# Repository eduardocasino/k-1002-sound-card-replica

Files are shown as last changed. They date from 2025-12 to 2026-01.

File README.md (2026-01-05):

# K-1002 8 bit audio Digital to Analog Converter replica

## About

This is a faithful replica of the K‑1002 8‑bit audio Digital‑to‑Analog Converter card for the KIM‑1, SYM‑1, and AIM‑65 computers, originally designed by MTU in the late ’70s.

I'm using the original K‑1002 documentation and high‑resolution photos from [Hans Otten's Retro Computing website](http://retro.hansotten.nl/).

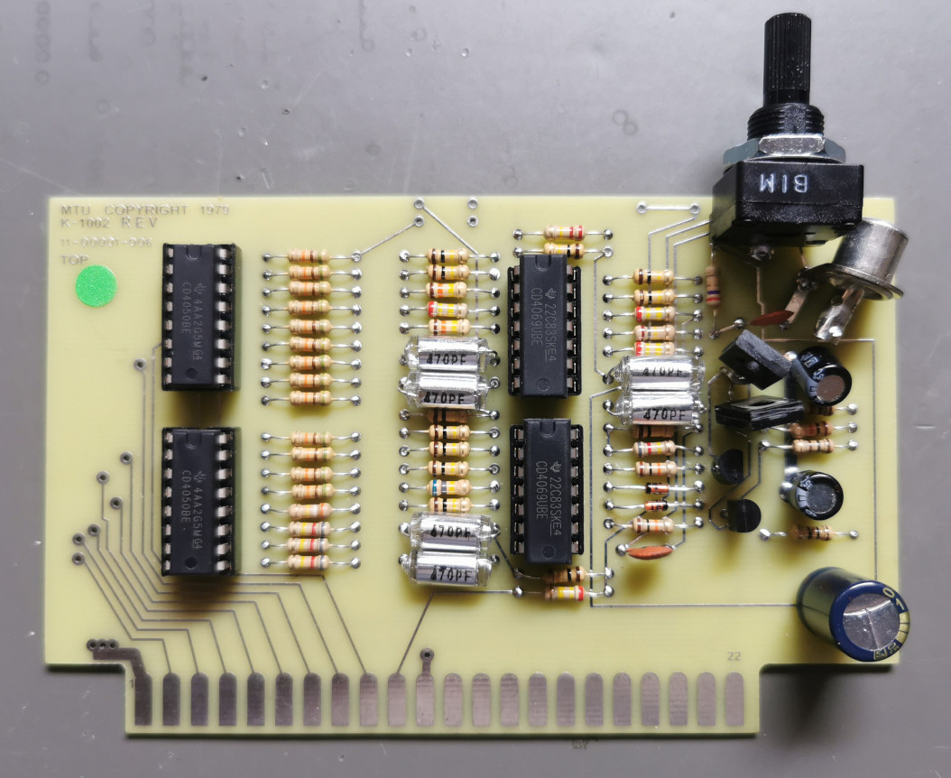
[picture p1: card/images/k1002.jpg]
finished card

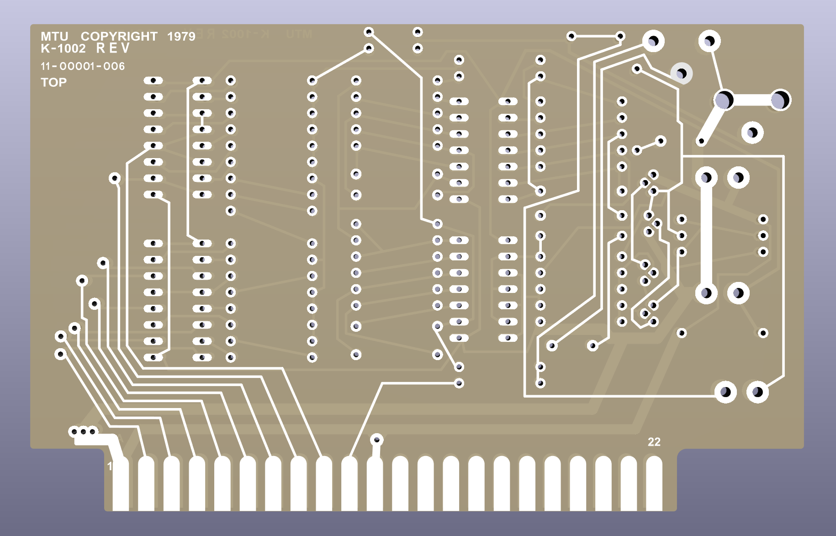
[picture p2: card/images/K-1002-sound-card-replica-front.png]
front

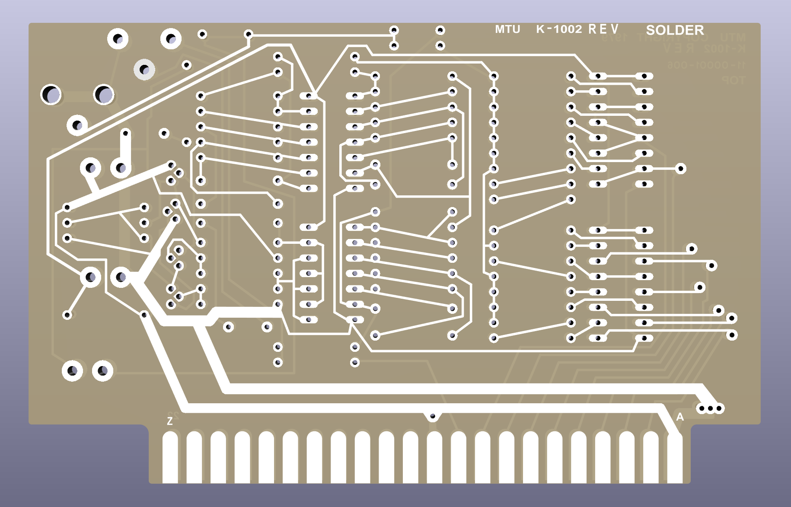
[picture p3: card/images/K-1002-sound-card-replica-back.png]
back


### Important!

Although the card uses the familiar 44‑pin edge connector, it’s not a 1‑to‑1 match for the KIM‑1 application bus, so an adapter is required, as explained in the manual. I’ve also designed such an adapter, which you can find in the `adapter` folder.

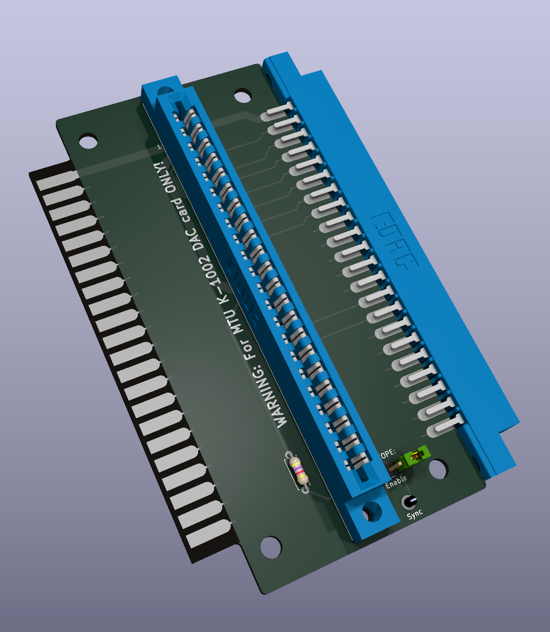
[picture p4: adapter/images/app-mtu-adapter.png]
adapter


## Building

There’s nothing particularly special about assembling the board. As with any other PCB, just start soldering components in order of height. All the ICs are socketed.

There’s a BOM spreadsheet in the `card/docs` folder, but there are a few things to keep in mind regarding some of the components:

* R1 to R13 are 51K resistors that need to be matched within 1%. You can either use modern metal‑film resistors with that tolerance or manually match carbon ones. I went with the latter to keep the look closer to the original.
Also, the documentation isn’t very clear about whether &plusmn;1% is actually enough or if it really means &plusmn;0.5% (so that all resistors fall within a 1% spread). I chose the latter interpretation as well.

* The 92PU01 and 92PU51 transistors are no longer available. The BD135‑10 and BD136‑10 are perfectly good functional replacements, but they use a different package and footprint, so you’ll need to bend the leads to fit them on the board.
 **NOTE**: They *must* be the "-10" variants!!

* The original potentiometer is no longer manufactured. A drop‑in replacement is the Piher PT15NH06 with the adjustment wheel. **NOTE**: Make sure you get the NH06 variant.

* The Keystone 571 RCA connector is no longer manufactured. Some suppliers may still have remaining stock, such as [TME](https://tme.eu) in Europe.

## KIM-1 Software and PC Utilities

I've only built it on a Debian Linux and on WSL with Ubuntu. I can't give support for other systems, sorry.

### Prerequisites

Any modern Linux distribution, tested on `Debian 12.6` and `Ubuntu 24.04`

Install the required packages:

```console
$ sudo apt update
$ sudo apt install build-essential cc65
```

### Build and usage

Just go to the `software` folder and run`make`:

```console
$ cd software
$ make
```

This will build the PC utilities and the KIM‑1 demo programs. The latter are generated in PAP format and are named with a numeric prefix that matches the file numbers in the K‑1002‑1L 8‑BIT Digital Music Software manual. Use them as instructed there.

Additionally, pcmplay.pap is a simple PCM player that plays a short sound snippet. Load it into your KIM-1 and run it at `$0200`.

The PC utilities are built into `software/utils/bin`:

* `wavegen` is a modern C version of the `kimfs` program. It generates a waveform table suitable for use with the MTU utilities from a very simle YAML description file.

* `notcmp` is the C version of the NOTRAN compiler. It accepts the same input files as its MTU counterpart and generates compatible object code for the NOTRAN interpreter.

* `notint` is a NOTRAN interpreter simulator that can either play a NOTRAN bytecode file through an ALSA device or generates WAV files to be played with any WAV player.

Run any of them without arguments to see the usage instructions.

## Licensing

This is a personal project that I am sharing in case it is of interest to any retrocomputing enthusiast and all the information in this repository is provided "as is", without warranty of any kind. I am not liable for any damages that may occur, whether it be to individuals, objects, KIM-1 computers, kittens or any other pets. **It should also be noted that everything in this repository is a work in progress and, although the board has been tested, may contain errors. Therefore, anyone who chooses to use it does so at their own risk**.

### Card



Th K-1002 replica is licensed under a [Creative Commons Attribution-NonCommercial 4.0 International License](http://creativecommons.org/licenses/by-nc/4.0/).

### Adapter



The adapter card is licensed under a [Creative Commons Attribution-ShareAlike 4.0 International License](http://creativecommons.org/licenses/by-sa/4.0/).

### MTU Software

Although it probably doesn’t matter much nowadays, since this software was written for a very obsolete and rare piece of hardware, the material is still copyrighted by MICRO TECHNOLOGY UNLIMITED, a company that is [still in business](http://www.mtu.com/catalog/index.php). I’m sharing it here solely to help anyone who owns a K‑1002 card.

### PC Utilities

All my code is licensed under the GNU General Public License, Version 3.

## Acknowledgements

* Hans Otten and his [Retro Computing blog](http://retro.hansotten.nl/). A lot of information and high resolution pictures of a K-1002

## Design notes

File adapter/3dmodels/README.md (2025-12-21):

Download the EDAC connector 3D model from here: https://files.edac.net/edac/content/307/307-044-520-202%20-%20EDAC%20Card%20Edge%20Connector.STEP

Jumper model by 
Dmitry Levin https://grabcad.com/library/jumper-2-54mm-pitch-1

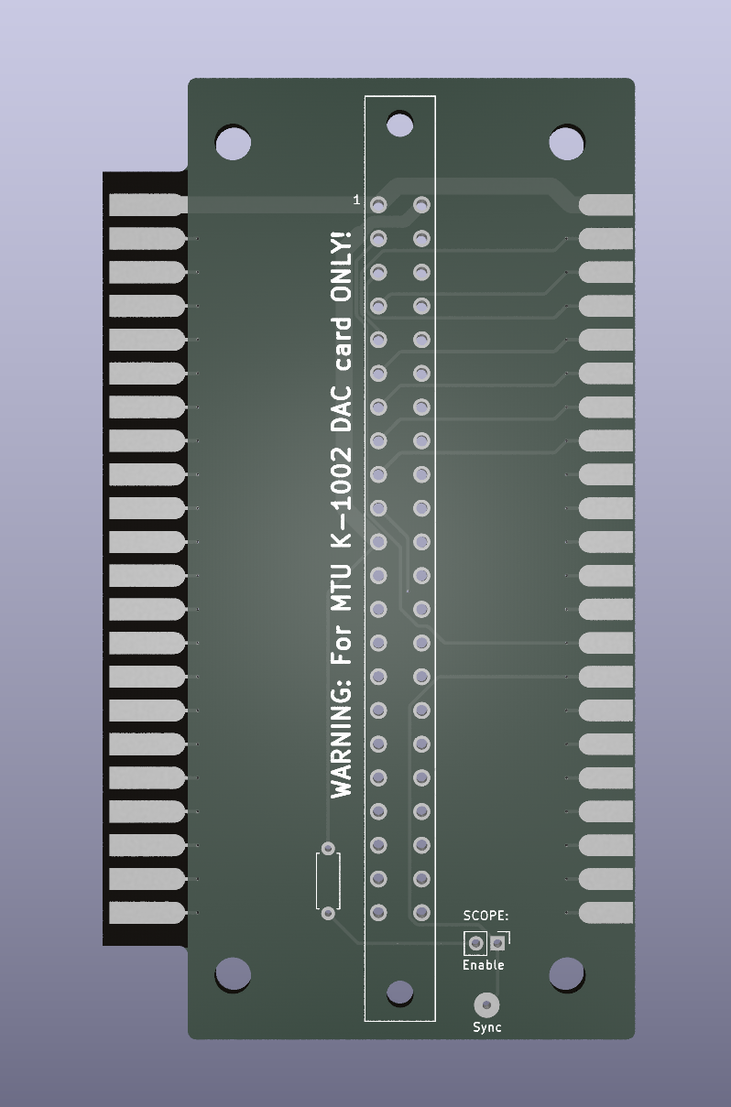
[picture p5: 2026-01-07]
adapter/images/app-mtu-adapter-front.png

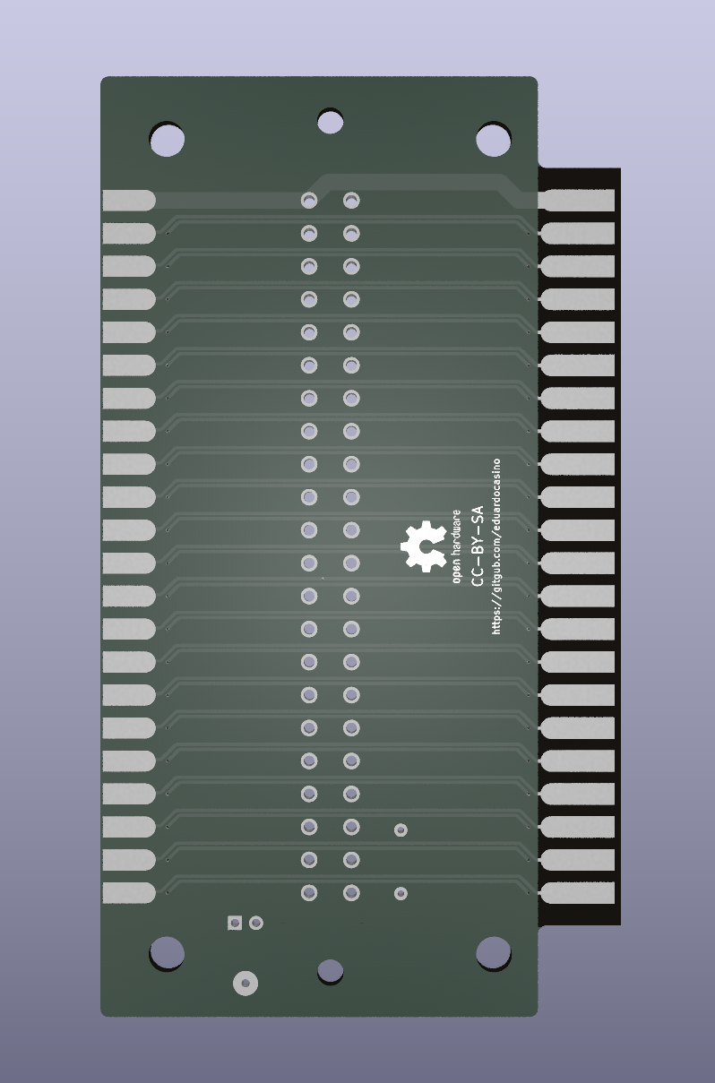
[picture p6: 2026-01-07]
adapter/images/app-mtu-adapter-back.png

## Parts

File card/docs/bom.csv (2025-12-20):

Reference | Qty | Type | Value | Notes
C1,C2,C3,C4,C5,C6 | 6 | polystyrene | 470p
C7,C9 | 2 | ceramic, 12V, Z5U | 100n
C8 | 1 | electrolytic, 10V | 1000u
C10,C11 | 2 | electrolytic, 6V | 220u
D1,D2 | 2 |  | 1N4148
P1 | 1 | RCA Keystone 571
Q1 | 1 |  | PN2907
Q2 | 1 |  | PN2222
Q3 | 1 |  | 92PU01 | Alternative: | BD135-10
Q4 | 1 |  | 92PU51 | Alternative: | BD136-10
R1,R2,R3,R4,R5,R6,R7,R8,R9,R10,R11,R12,R13 | 13 | Carbon, 0.25W | 51K | Matched to 1%
R14 | 1 | Carbon, 0.25W | 390K
R15,R16,R17,R38 | 4 | Carbon, 0.25W | 820K
R18,R19,R23,R24,R25,R26,R28,R30,R31,R32,R33,R37 | 12 | Carbon, 0.25W | 100K
R20,R22 | 2 | Carbon, 0.25W | 130K
R21,R34,R36,R45 | 4 | Carbon, 0.25W | 240K
R27 | 1 | Carbon, 0.25W | 680K
R29 | 1 | Carbon, 0.25W | 220K
R35 | 1 | Carbon, 0.25W | 180K
R39,R40 | 2 | Carbon, 0.25W | 10K
R41,R43 | 2 | Carbon, 0.25W | 100R
R42 | 1 | Carbon, 0.25W | 1K
R44 | 1 | Carbon, 0.25W | 10R
R46 | 1 | Carbon, 0.25W | 2R7
R47 | 1 | Piher PT15NH06 | 1M | Alternative: | 16PMI-1MSR PASSIVES
U1,U2 | 2 |  | CD4050
U3,U4 | 2 |  | CD4069

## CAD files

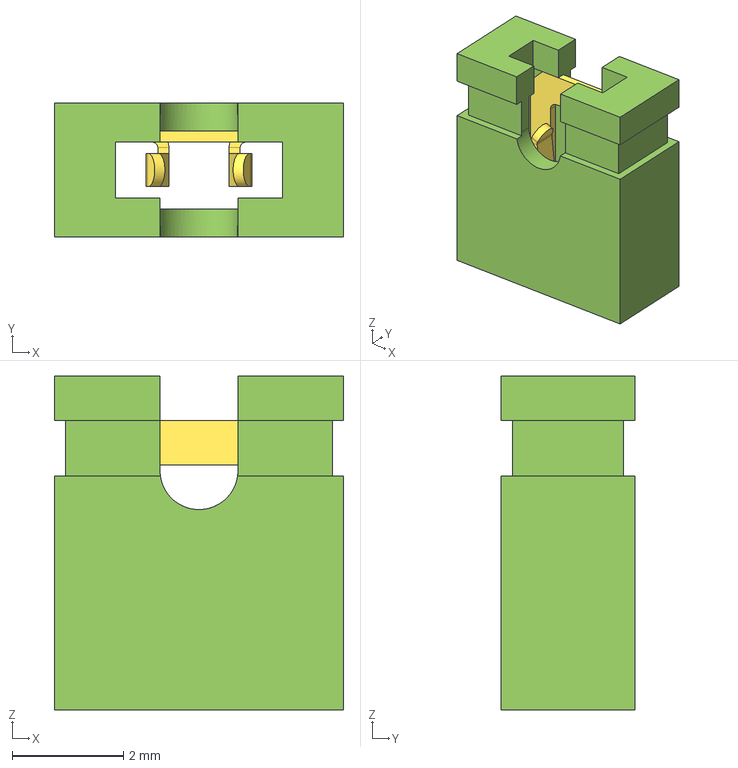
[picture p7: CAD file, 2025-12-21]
adapter/3dmodels/Jumper-green.step
5.20 x 2.40 x 6.00 mm

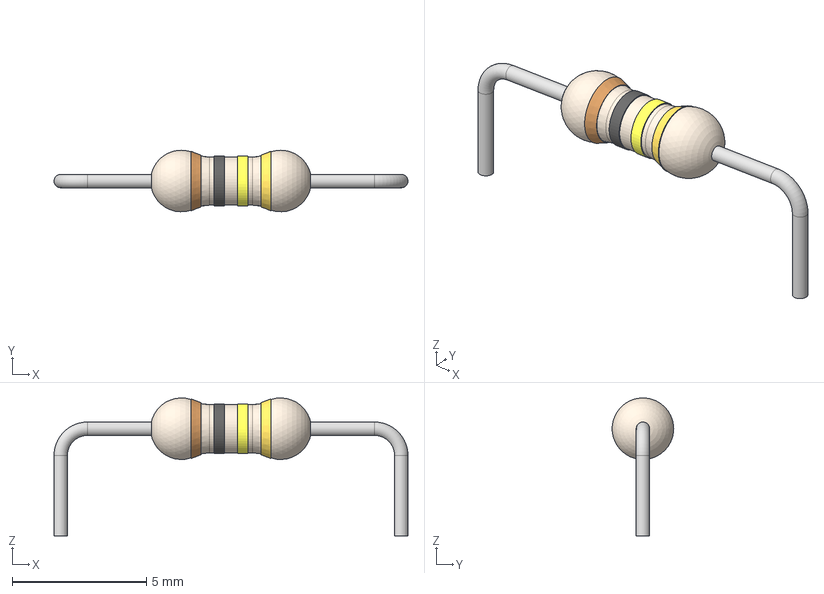
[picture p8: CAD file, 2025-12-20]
card/3dmodels/res-1_4w-100K-12_7mm.step
13.2 x 2.29 x 5.14 mm
Resistor-body
Ring-1
Ring-2
Ring-3
Ring-4
pins

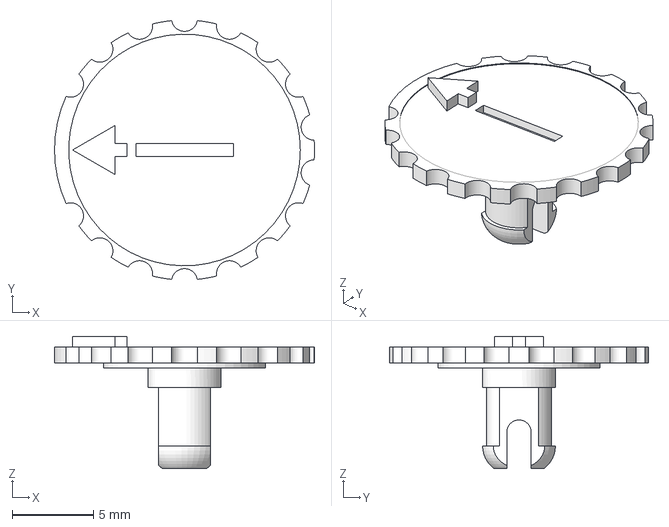
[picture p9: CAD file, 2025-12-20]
card/3dmodels/Piher_5371_.stp
16.0 x 15.9 x 8.15 mm

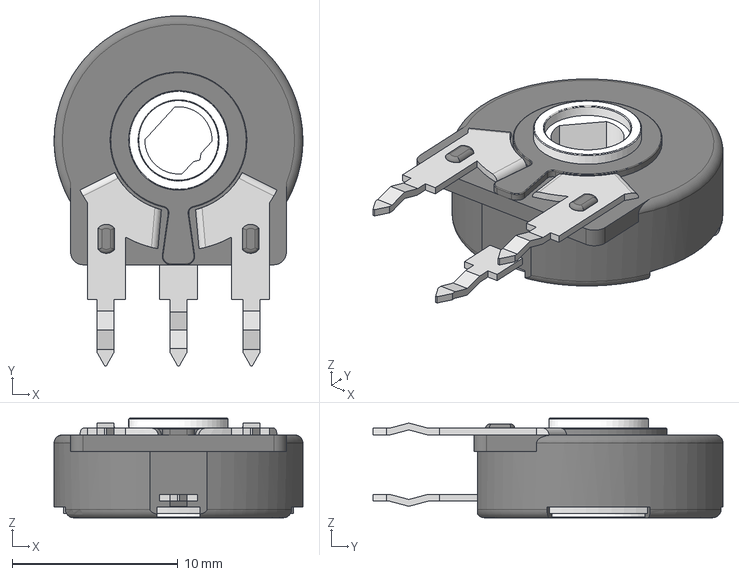
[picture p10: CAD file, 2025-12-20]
card/3dmodels/Piher_PT15NH06.stp
15.0 x 21.1 x 6.00 mm

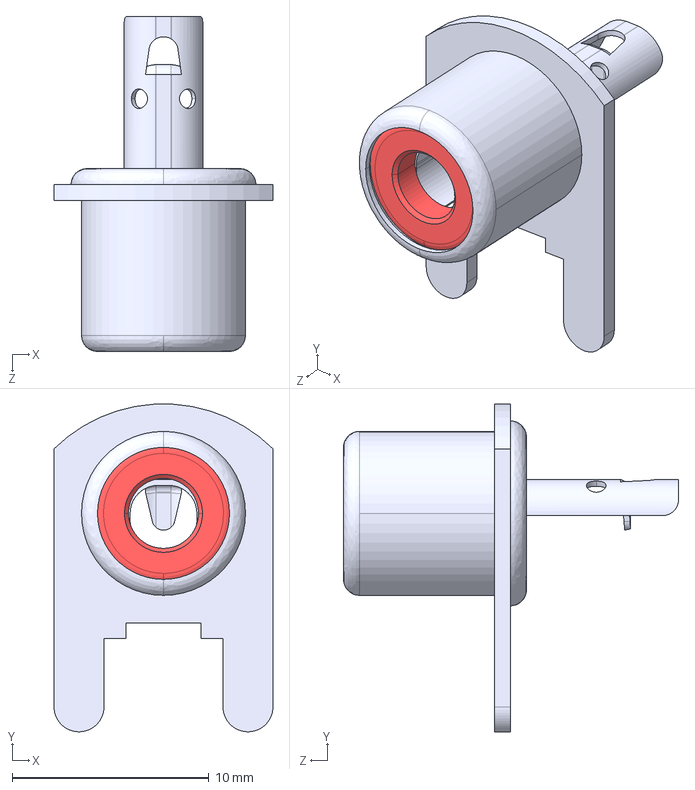
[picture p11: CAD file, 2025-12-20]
card/3dmodels/571.stp
11.1 x 16.6 x 17.0 mm

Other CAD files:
card/3dmodels/res-1_4w-10R-12_7mm.step
card/3dmodels/res-1_4w-130K-12_7mm.step
card/3dmodels/res-1_4w-820K-12_7mm.step
card/3dmodels/res-1_4w-51K-12_7mm.step
card/3dmodels/res-1_4w-100R-12_7mm.step
card/3dmodels/res-1_4w-1K-12_7mm.step
card/3dmodels/res-1_4w-180K-12_7mm.step
card/3dmodels/res-1_4w-10K-12_7mm.step
card/3dmodels/res-1_4w-680K-12_7mm.step
card/3dmodels/res-1_4w-390K-12_7mm.step
card/3dmodels/res-1_4w-240K-12_7mm.step
card/3dmodels/res-1_4w-2R7-12_7mm.step
card/3dmodels/res-1_4w-220K-12_7mm.step

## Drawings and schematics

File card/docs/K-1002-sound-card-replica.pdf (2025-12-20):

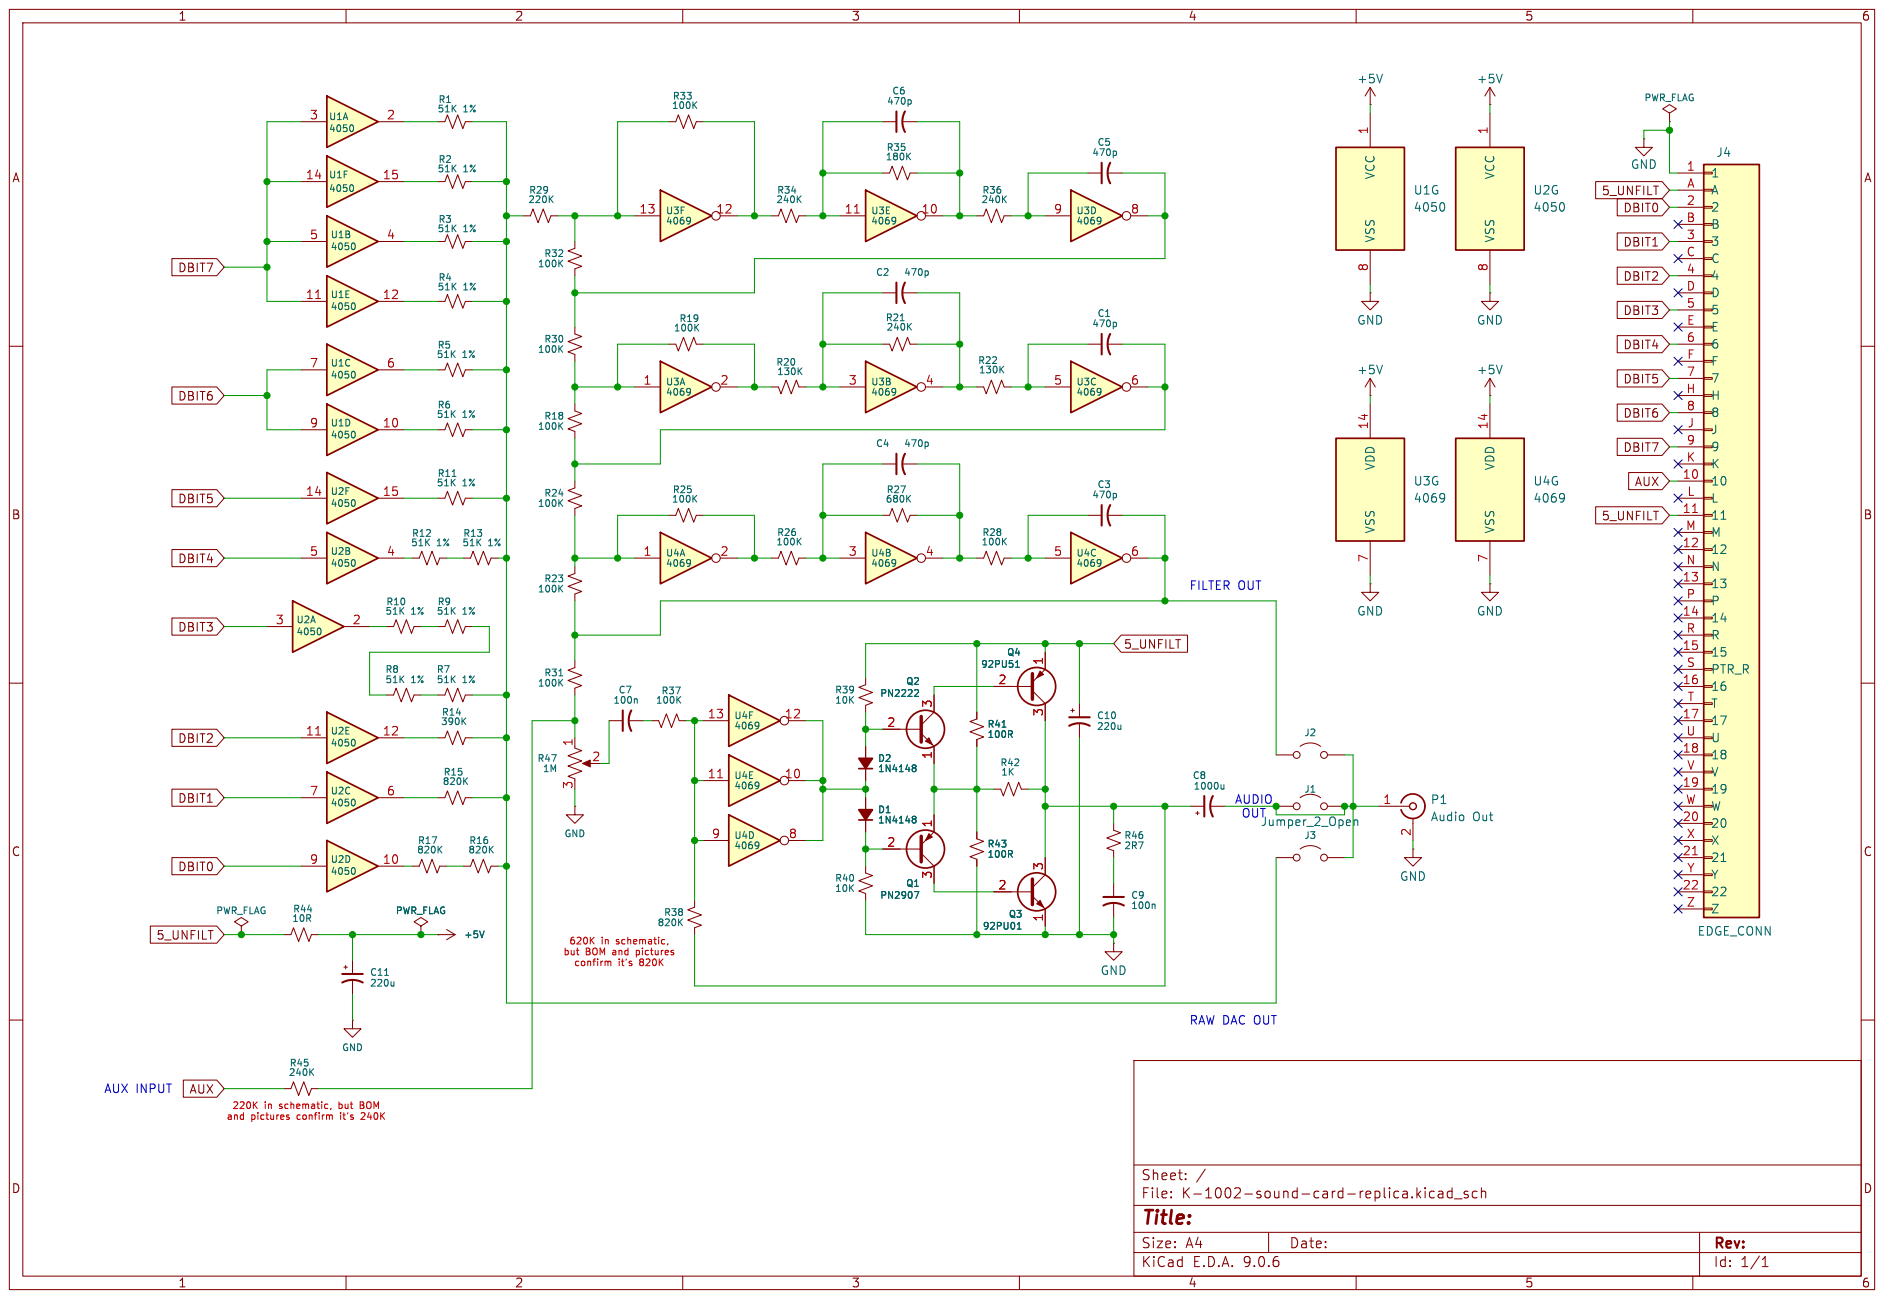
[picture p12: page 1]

620K in schematic, but BOM and pictures

Id: 1/1 Title: File: K-1002-sound-card-replica.kicad_sch Sheet: /

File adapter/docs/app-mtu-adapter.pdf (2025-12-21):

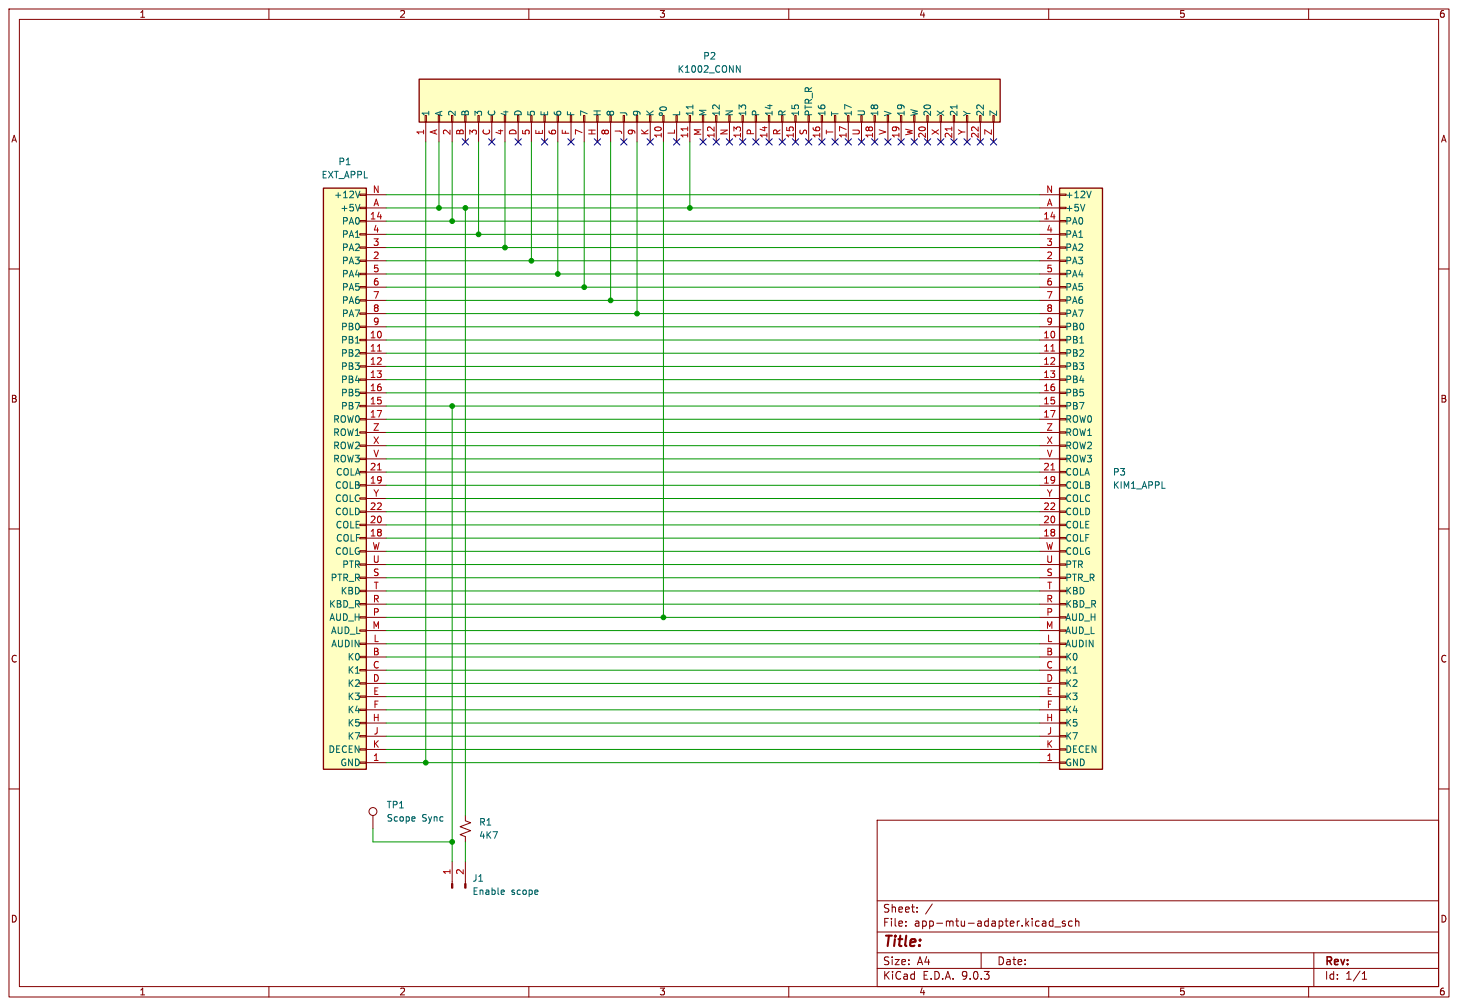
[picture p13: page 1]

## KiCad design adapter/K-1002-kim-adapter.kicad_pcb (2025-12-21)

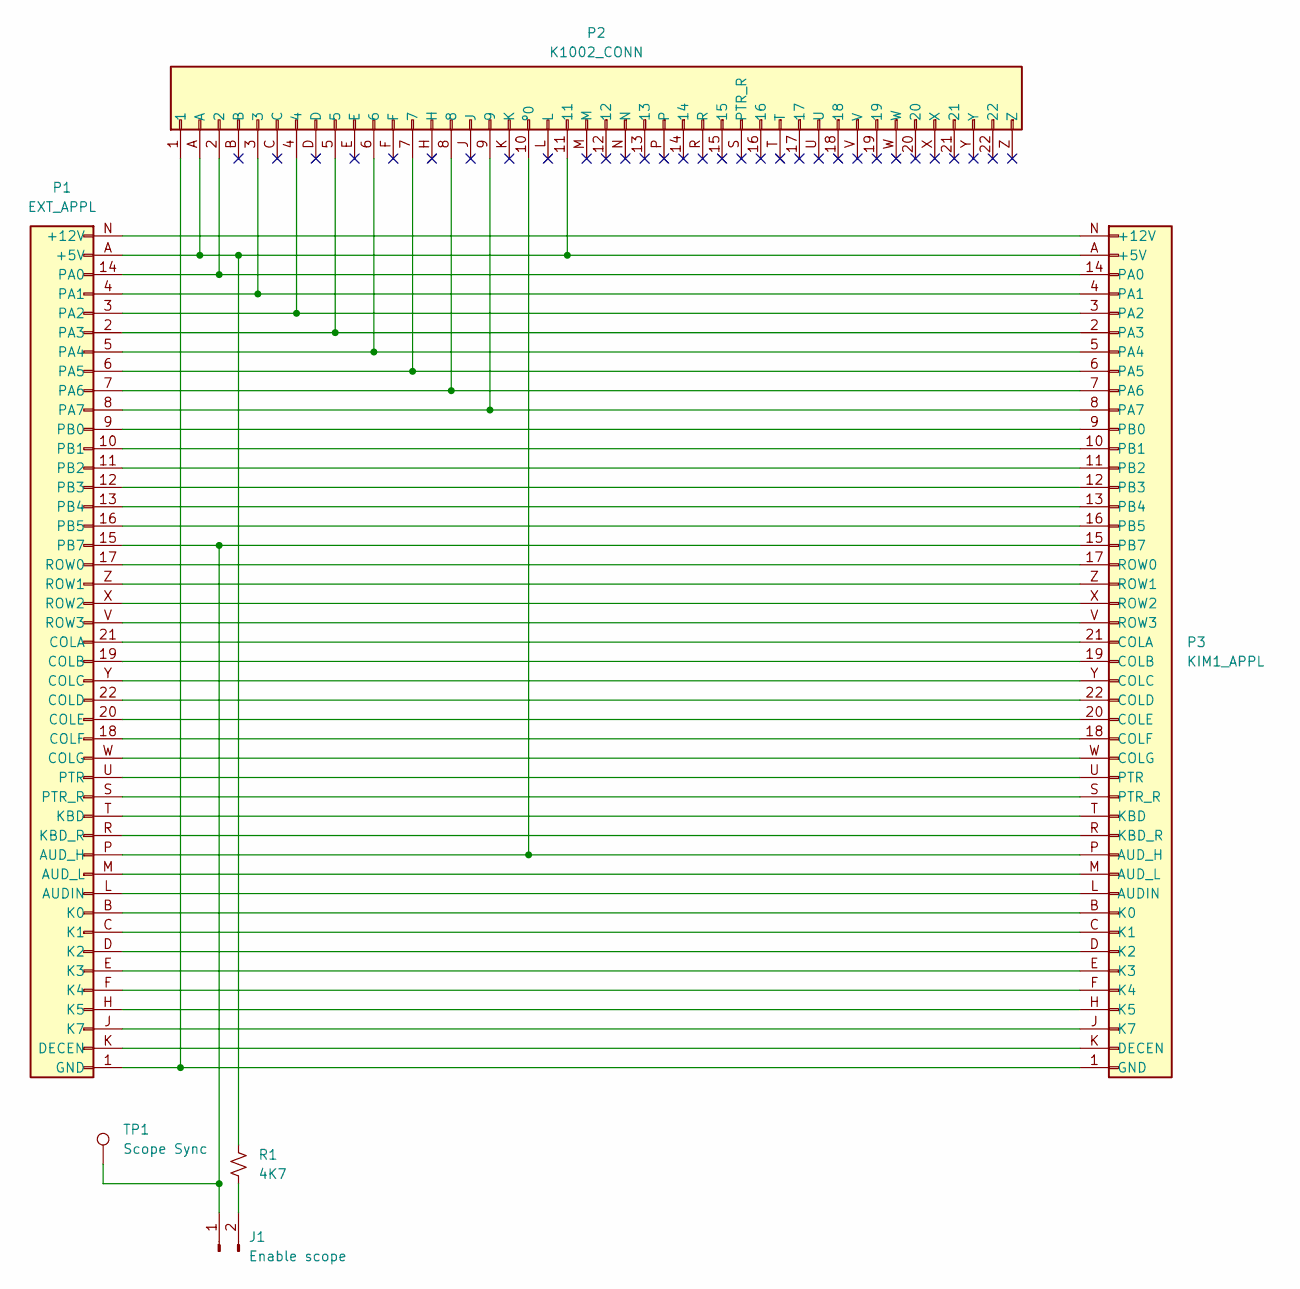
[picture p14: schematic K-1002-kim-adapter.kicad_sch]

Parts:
J1: Enable scope; PinHeader_1x02_P2.54mm_Vertical
P1: EXT_APPL; KIM_EDGE
P2: K1002_CONN; EDAC-3.96-2x22
P3: KIM1_APPL; APPL_CONN
R1: 4K7; R_Axial_DIN0207_L6.3mm_D2.5mm_P7.62mm_Horizontal
TP1: Scope Sync; TestPoint_3.0

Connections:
unnamed: J1.1, P1.15 (PB7), P3.15 (PB7), TP1.1
unnamed: J1.2, R1.2
unnamed: P1.A (+5V), P2.11, P2.A, P3.A (+5V), R1.1
unnamed: P1.N (+12V), P3.N (+12V)
unnamed: P1.L (AUDIN), P3.L (AUDIN)
unnamed: P1.P (AUD_H), P2.10 (º0), P3.P (AUD_H)
unnamed: P1.M (AUD_L), P3.M (AUD_L)
unnamed: P1.21 (COLA), P3.21 (COLA)
unnamed: P1.19 (COLB), P3.19 (COLB)
unnamed: P1.Y (COLC), P3.Y (COLC)
unnamed: P1.22 (COLD), P3.22 (COLD)
unnamed: P1.20 (COLE), P3.20 (COLE)
unnamed: P1.18 (COLF), P3.18 (COLF)
unnamed: P1.W (COLG), P3.W (COLG)
unnamed: P1.K (DECEN), P3.K (DECEN)
unnamed: P1.1 (GND), P2.1, P3.1 (GND)
unnamed: P1.B (K0), P3.B (K0)
unnamed: P1.C (K1), P3.C (K1)
unnamed: P1.D (K2), P3.D (K2)
unnamed: P1.E (K3), P3.E (K3)
unnamed: P1.F (K4), P3.F (K4)
unnamed: P1.H (K5), P3.H (K5)
unnamed: P1.J (K7), P3.J (K7)
unnamed: P1.T (KBD), P3.T (KBD)
unnamed: P1.R (KBD_R), P3.R (KBD_R)
unnamed: P1.14 (PA0), P2.2, P3.14 (PA0)
unnamed: P1.4 (PA1), P2.3, P3.4 (PA1)
unnamed: P1.3 (PA2), P2.4, P3.3 (PA2)
unnamed: P1.2 (PA3), P2.5, P3.2 (PA3)
unnamed: P1.5 (PA4), P2.6, P3.5 (PA4)
unnamed: P1.6 (PA5), P2.7, P3.6 (PA5)
unnamed: P1.7 (PA6), P2.8, P3.7 (PA6)
unnamed: P1.8 (PA7), P2.9, P3.8 (PA7)
unnamed: P1.9 (PB0), P3.9 (PB0)
unnamed: P1.10 (PB1), P3.10 (PB1)
unnamed: P1.11 (PB2), P3.11 (PB2)
unnamed: P1.12 (PB3), P3.12 (PB3)
unnamed: P1.13 (PB4), P3.13 (PB4)
unnamed: P1.16 (PB5), P3.16 (PB5)
unnamed: P1.U (PTR), P3.U (PTR)
unnamed: P1.S (PTR_R), P3.S (PTR_R)
unnamed: P1.17 (ROW0), P3.17 (ROW0)
unnamed: P1.Z (ROW1), P3.Z (ROW1)
unnamed: P1.X (ROW2), P3.X (ROW2)
unnamed: P1.V (ROW3), P3.V (ROW3)

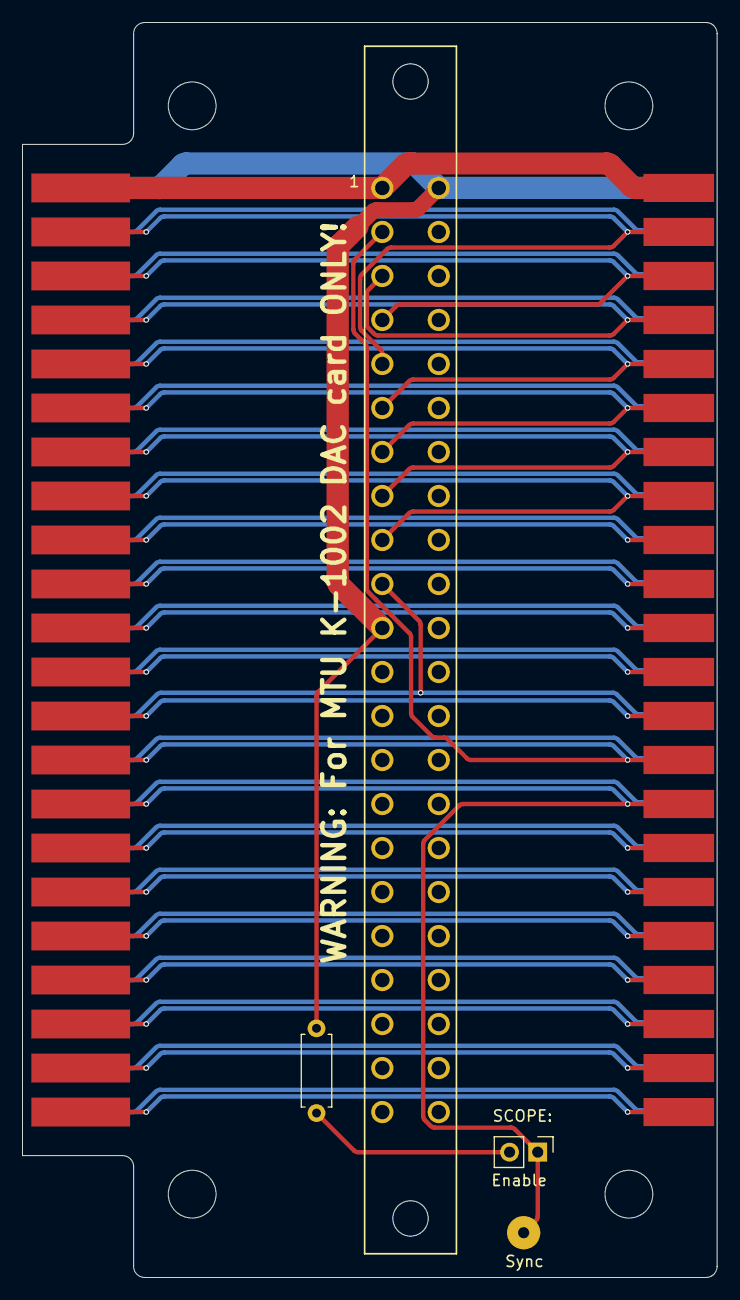
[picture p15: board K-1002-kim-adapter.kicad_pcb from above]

Board: 2 copper layers, 62.5 x 112.9 mm, 10 parts (0 on the bottom side), 45 nets.

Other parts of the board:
M1, M1#2, M1#3, M2: MountingHole_4.3mm_M4

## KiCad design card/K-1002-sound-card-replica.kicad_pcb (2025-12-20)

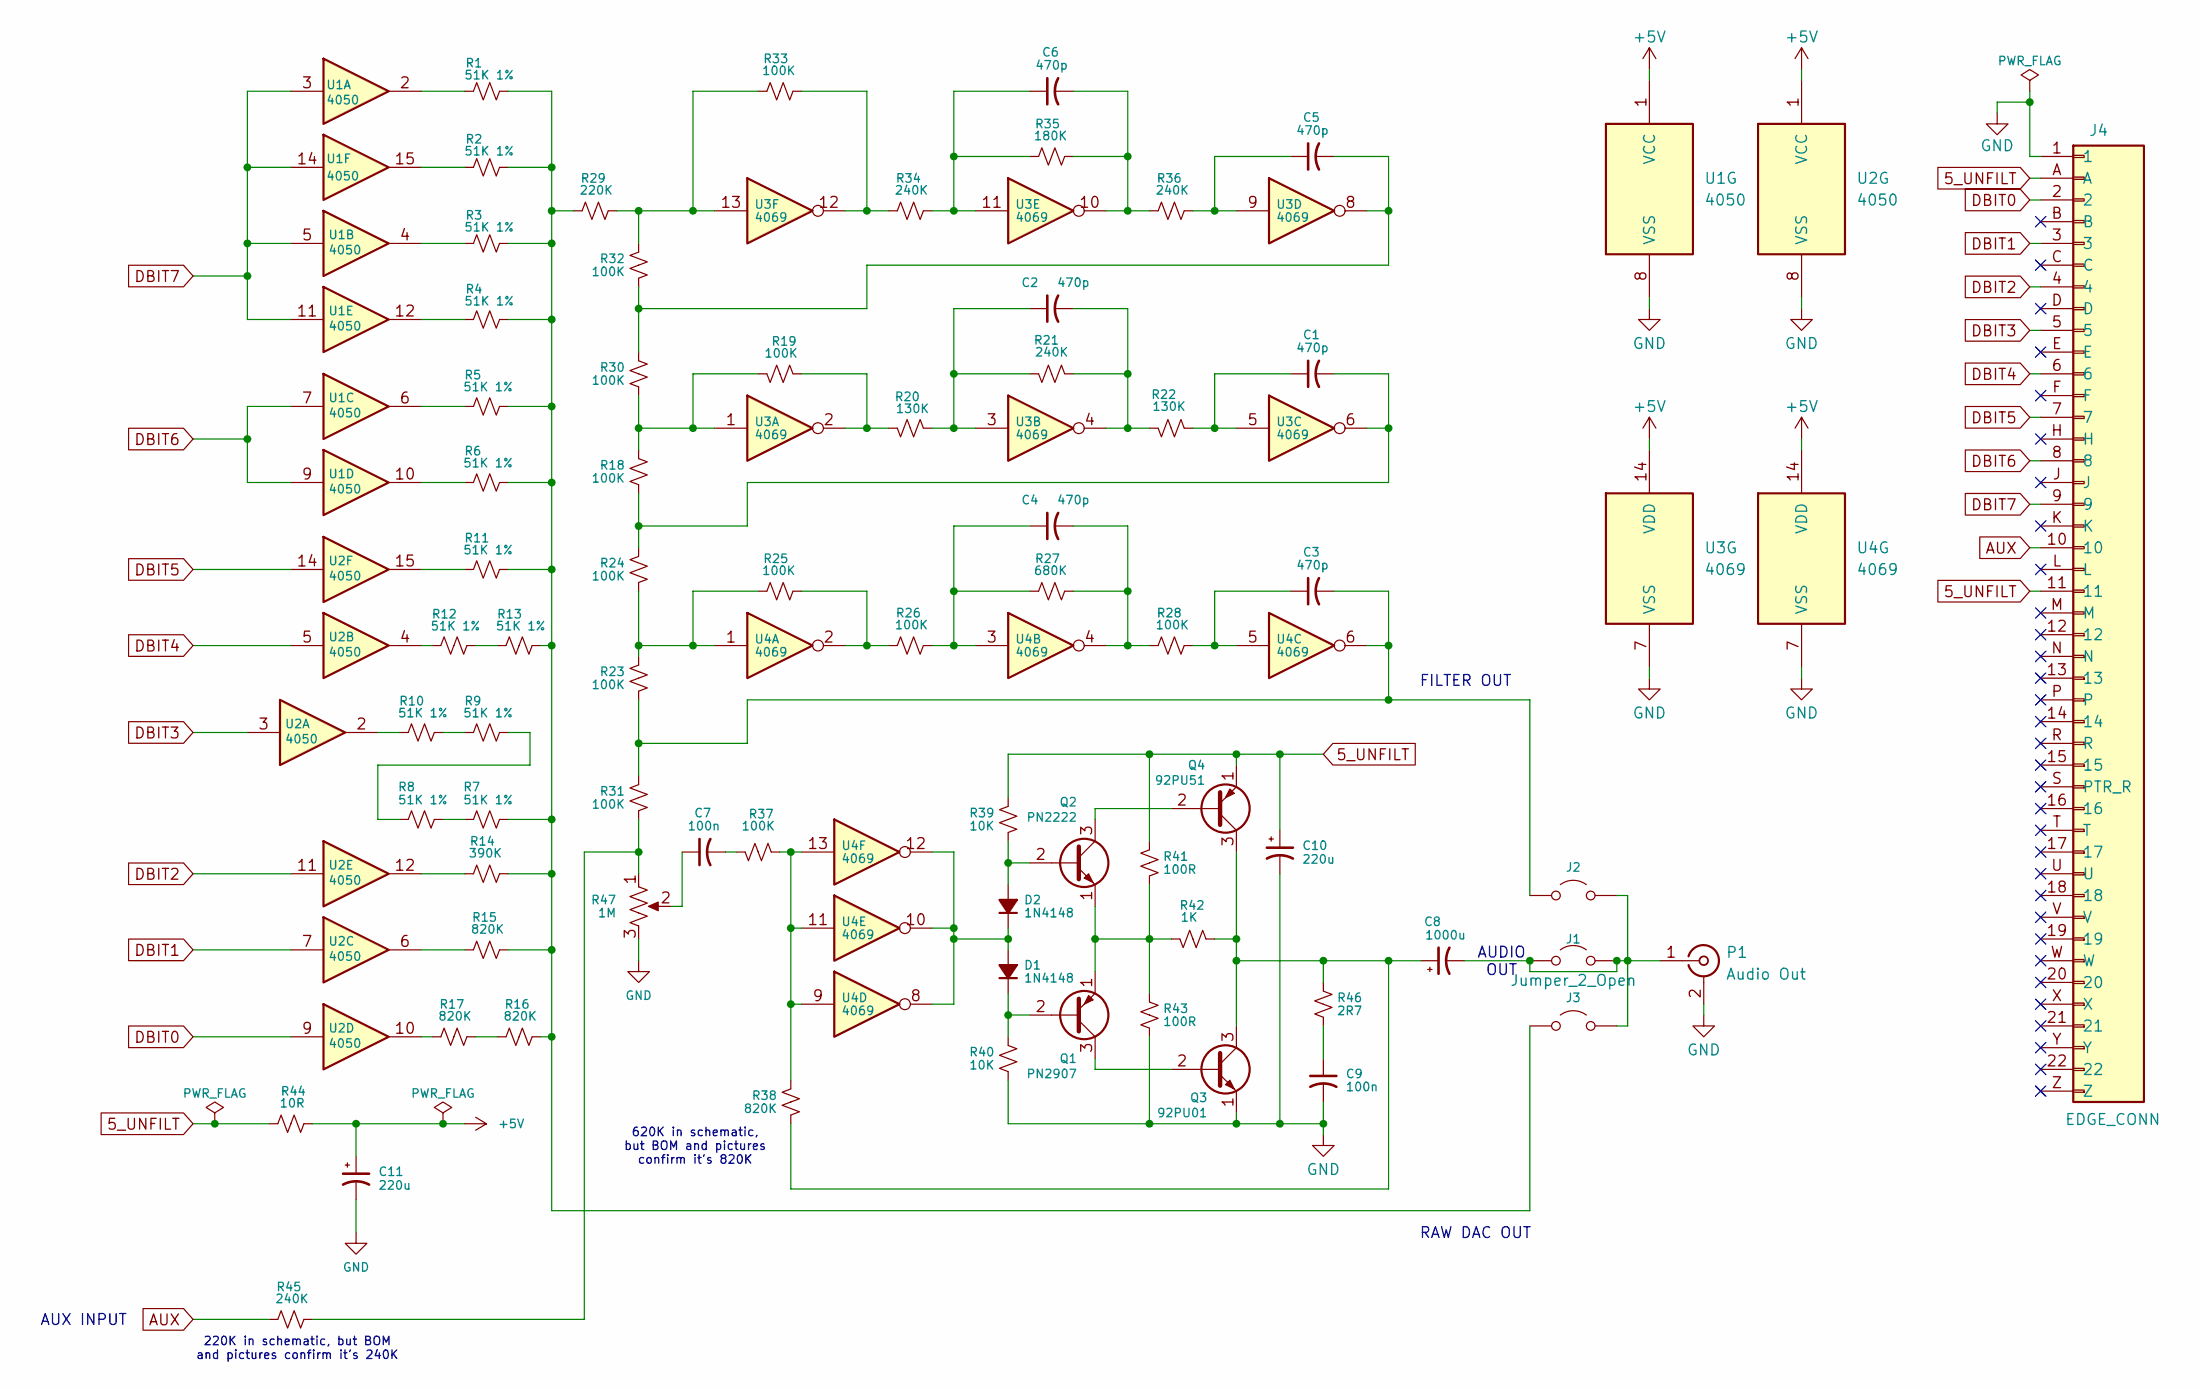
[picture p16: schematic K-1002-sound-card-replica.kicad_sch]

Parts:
C1, C2, C3, C4, C5, C6: 470p; C_Axial_L10.3mm_D4.7mm_P12.70mm_Horizontal
C7, C9: 100n; C_Disc_D7.0mm_W2.5mm_P6.35mm
C8: 1000u; C_Radial_D12.5mm_H20.0mm_P5.00mm
C10, C11: 220u; C_Radial_D10.0mm_H12.5mm_P5.00mm
D1, D2: 1N4148; D_DO-35_SOD27_P12.70mm_Horizontal
J1, J2, J3: Jumper_2_Open; Bridge_Open_P7.62mm
J4: EDGE_CONN
P1: Audio Out; Keystone_571_RCA
Q1: PN2907; TO-92-Custom
Q2: PN2222; TO-92-Custom
Q3: 92PU01; TO-92-Custom
Q4: 92PU51; TO-92-Custom
R1, R2, R3, R4, R5, R6, R7, R8, R9, R10, R11, R12, R13: 51K 1%; R_Axial_DIN0204_L3.6mm_D2.5mm_P12.70mm_Horizontal_51K
R14: 390K; R_Axial_DIN0204_L3.6mm_D2.5mm_P12.70mm_Horizontal_390K
R15, R16, R17, R38: 820K; R_Axial_DIN0204_L3.6mm_D2.5mm_P12.70mm_Horizontal_820K
R18, R19, R23, R24, R25, R26, R28, R30, R31, R32, R33, R37: 100K; R_Axial_DIN0204_L3.6mm_D2.5mm_P12.70mm_Horizontal_100K
R20, R22: 130K; R_Axial_DIN0204_L3.6mm_D2.5mm_P12.70mm_Horizontal_130K
R21, R34, R36, R45: 240K; R_Axial_DIN0204_L3.6mm_D2.5mm_P12.70mm_Horizontal_240K
R27: 680K; R_Axial_DIN0204_L3.6mm_D2.5mm_P12.70mm_Horizontal_680K
R29: 220K; R_Axial_DIN0204_L3.6mm_D2.5mm_P12.70mm_Horizontal_220K
R35: 180K; R_Axial_DIN0204_L3.6mm_D2.5mm_P12.70mm_Horizontal_180K
R39, R40: 10K; R_Axial_DIN0204_L3.6mm_D2.5mm_P12.70mm_Horizontal_10K
R41, R43: 100R; R_Axial_DIN0204_L3.6mm_D2.5mm_P12.70mm_Horizontal_100R
R42: 1K; R_Axial_DIN0204_L3.6mm_D2.5mm_P12.70mm_Horizontal_1K
R44: 10R; R_Axial_DIN0204_L3.6mm_D2.5mm_P12.70mm_Horizontal_10R
R46: 2R7; R_Axial_DIN0204_L3.6mm_D2.5mm_P12.70mm_Horizontal_2R7
R47: 1M; Piher_PT15-NH-06
U1, U2: 4050; DIP-16_W7.62mm_LongPads
U3, U4: 4069; DIP-14_W7.62mm_LongPads

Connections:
5_UNFILT: C10.1, J4.11, J4.A, Q4.1 (E), R39.1, R41.2, R44.1
+5V: C11.1, R44.2, U1.1 (VCC), U1.16, U2.1 (VCC), U2.16, U3.14 (VDD), U4.14 (VDD)
AUX: J4.10 (º0), R45.1
DBIT0: J4.2, U2.9
DBIT1: J4.3, U2.7
DBIT2: J4.4, U2.11
DBIT3: J4.5, U2.3
DBIT4: J4.6, U2.5
DBIT5: J4.7, U2.14
DBIT6: J4.8, U1.7, U1.9
DBIT7: J4.9, U1.3, U1.5, U1.11, U1.13, U1.14
GND: C9.2, C10.2, C11.2, J4.1, P1.2 (Ext), Q3.1 (E), R40.1, R43.2, R47.3, U1.8 (VSS), U2.8 (VSS), U3.7 (VSS), U4.7 (VSS)
unnamed: C1.1, R22.1, U3.5
unnamed: C1.2, R18.1, R24.1, U3.6
unnamed: C2.1, R20.1, R21.2, U3.3
unnamed: C2.2, R21.1, R22.2, U3.4
unnamed: C3.1, R28.2, U4.5
unnamed: C4.1, R26.2, R27.1, U4.3
unnamed: C4.2, R27.2, R28.1, U4.4
unnamed: C5.1, R36.2, U3.9
unnamed: C5.2, R30.2, R32.2, U3.8
unnamed: C6.1, R34.2, R35.1, U3.11
unnamed: C6.2, R35.2, R36.1, U3.10
unnamed: C7.1, R47.2
unnamed: C7.2, R37.2
unnamed: C9.1, R46.2
unnamed: D1.2 (A), D2.1 (K), U4.8, U4.10, U4.12
unnamed: D1.1 (K), Q1.2 (B), R40.2
unnamed: D2.2 (A), Q2.2 (B), R39.2
unnamed: C8.2, J1.1 (A), J1.2 (B), J2.2 (B), J3.2 (B), P1.1 (In)
unnamed: C3.2, J2.1 (A), R23.2, R31.1, U4.6
unnamed: J3.1 (A), R1.2, R2.2, R3.2, R4.2, R5.2, R6.2, R7.2, R11.2, R13.2, R14.2, R15.2, R16.2, R29.1
unnamed: Q1.3 (C), Q3.2 (B)
unnamed: Q1.1 (E), Q2.1 (E), R41.1, R42.2, R43.1
unnamed: Q2.3 (C), Q4.2 (B)
unnamed: C8.1, Q3.3 (C), Q4.3 (C), R38.2, R42.1, R46.1
unnamed: R1.1, U1.2
unnamed: R2.1, U1.15
unnamed: R3.1, U1.4
unnamed: R4.1, U1.12
unnamed: R5.1, U1.6
unnamed: R6.1, U1.10
unnamed: R7.1, R8.2
unnamed: R8.1, R9.2
unnamed: R10.1, U2.2
unnamed: R9.1, R10.2
unnamed: R11.1, U2.15
unnamed: R12.1, U2.4, U2.13
unnamed: R12.2, R13.1
unnamed: R14.1, U2.12
unnamed: R15.1, U2.6
unnamed: R16.1, R17.2
unnamed: R17.1, U2.10
unnamed: R18.2, R19.2, R30.1, U3.1
unnamed: R19.1, R20.2, U3.2
unnamed: R23.1, R24.2, R25.1, U4.1
unnamed: R25.2, R26.1, U4.2
unnamed: R29.2, R32.1, R33.1, U3.13
unnamed: R31.2, R45.2, R47.1
unnamed: R33.2, R34.1, U3.12
unnamed: R37.1, R38.1, U4.9, U4.11, U4.13

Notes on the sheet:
220K in schematic, but BOM and pictures confirm it's 240K
AUDIO OUT
RAW DAC OUT
620K in schematic, but BOM and pictures confirm it's 820K
AUX INPUT
FILTER OUT

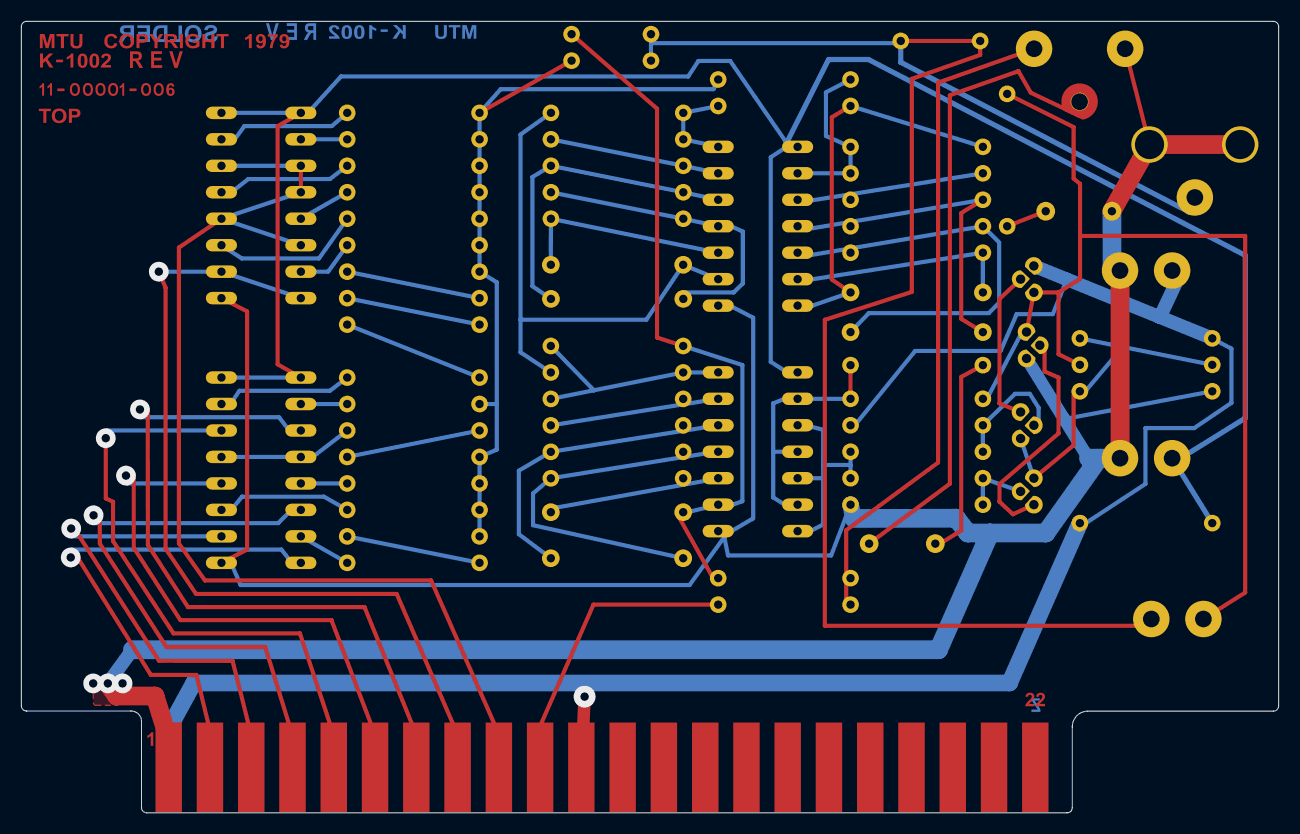
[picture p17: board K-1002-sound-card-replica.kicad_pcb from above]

Board: 2 copper layers, 120.7 x 76.0 mm, 73 parts (0 on the bottom side), 61 nets.

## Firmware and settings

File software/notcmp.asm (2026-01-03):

;        COPYRIGHT 1977 BY MICRO TECHNOLOGY UNLIMITED, BOX 4596,
;        MANCHESTER, NEW HAMPSHIRE 03108
;        PROGRAM WRITTEN BY HAL CHAMBERLIN

;        THIS PROGRAM COMPILES A SIMPLIFIED SUBSET OF THE NOTRAN MUSIC
;        LANGUAGE INTO AN OBJECT CODE STRING FOR PLAYING BY THE KIM
;        NOTRAN INTERPRETER.

;        LINES OF NOTRAN SOURCE CODE ARE PROCESSED BY THE COMPILER AND
;        CONVERTED INTO A SERIES OF OBJECT CODE BYTES WHICH ARE STORED
;        IN MEMORY AND LINES OF OBJECT CODE LISTING WHICH ARE PRINTED BY
;        AN OUTPUT DEVICE.  IF A CONTROLLABLE INPUT DEVICE IS AVAILABLE
;        (ONE THAT CAN BE STARTED AND STOPPED UNDER PROGRAM CONTROL)
;        THEN ONLY ONE LINE OF SOURCE CODE NEEDS TO BE IN MEMORY AT
;        ONCE.  STORAGE SPACE IS ALSO REQUIRED FOR A SMALL SYMBOL TABLE
;        WHICH NEEDS 3 BYTES PER SYMBOL.  SEE THE PROGRAM LISTING FOR
;        ADDRESS VECTORS AND SIZES OF THE SYMBOL TABLE, OBJECT CODE
;        AREA, LINE INPUT BUFFER, AND LINE OUTPUT BUFFER.

;        NOTRAN SOURCE IS MADE UP OF LINES.  A LINE MAY HAVE AN OPTIONAL
;        IDENTIFIER AND MAY CONSIST OF ONE OR MORE SPECIFICATIONS.  THE
;        IDENTIFIER, IF PRESENT, MUST BE IN THE FIRST CHARACTER POSITION
;        OF THE LINE.  AN IDENTIFIER IS A UNIQUE NUMBER BETWEEN 1 AND
;        255.  IF THERE IS NO IDENTIFIER, THE FIRST CHARACTER POSITION
;        MUST BE BLANK.  IF THE FIRST CHARACTER OF A LINE IS AN *, THEN
;        THE ENTIRE LINE IS TREATED AS A COMMENT.

;        A SPECIFICATION MAY EITHER BE A KEYWORD SPECIFICATION OR A NOTE
;        SPECIFICATION.  A KEYWORD SPECIFICATION MAY BE EITHER
;        EXECUTABLE IF OBJECT CODE BYTES ARE GENERATED FOR IT OR
;        NON-EXECUTABLE IF IT ONLY INFLUENCES FUTURE COMPILER ACTIONS.  A
;        KEYWORD SPECIFICATION CONSISTS OF A THREE LETTER KEYWORD
;        FOLLOWED BY OPTIONAL PARAMETERS SEPARATED BY COMMAS.  A NOTE
;        SPECIFICATION CONSISTS OF A STRING OF CHARACTERS TO BE DEFINED
;        LATER.  MULTIPLE SPECIFICATIONS ON ONE LINE MUST BE SEPARATED
;        BY SEMICOLONS.  ANY NUMBER OF BLANKS (INCLUDING ZERO) MAY BE
;        INSERTED BEFORE AND AFTER SEMICOLONS, BETWEEN A KEYWORD AND ITS
;        PARAMETERS, AND BEFORE THE FIRST SPECIFICATION ON A LINE,
;        BLANKS MAY NOT APPEAR IN THE MIDDLE OF A NOTE SPECIFICATION.
;        MAXIMUM INPUT LINE LENGTH IS 72 CHARACTERS.

;        DUE TO THE ONE-PASS SIMPLIFIED NATURE OF THE COMPILER, FORWARD
;        REFERENCING IN JUMP AND JUMP TO SUBROUTINE STATEMENTS IS NOT
;        SUPPORTED.  A BLOCK OF STATEMENTS MAY HOWEVER BE DEFINED AND A
;        JUMP CREATED TO SKIP FORWARD OVER IT.  THE BEGINNING OF THE
;        BLOCK IS DEFINED BY A "SUB" STATEMENT AND THE END IS DEFINED BY
;        AN "ESB" STATEMENT.  A JUMP IS CREATED AT THE "SUB" STATEMENT
;        WHICH IS DIRECTED TO THE STATEMENT FOLLOWING THE "ESB".  THIS
;        IN EFFECT DEFINES A FORWARD REFERENCE JUMP THAT MAY BE USED TO
;        JUMP OVER SUBROUTINE DEFINITIONS.  ONLY ONE "SUB-ESB" PAIR MAY
;        BE ACTIVE AT A TIME.

;        THE KEYWORD SPECIFICATIONS RECOGNIZED ARE AS FOLLOWS (X IS A
;        NUMERICAL PARAMETER):
;               NVC X        DEFINE NUMBER OF VOICES TO MIX, X IS IN
;                            RANGE IF 1-4 (SEE INTERPRETER LISTING)
;                            (EXECUTABLE)
;               ACT X,X,..,X ACTIVATE VOICE(S) X, X IN RANGE OF 1-4,
;                            (EXECUTABLE)
;               DCT X,X,..,X DEACTIVATE VOICE(S) X (EXECUTABLE)
;               WAV X,Y      ASSIGN WAVEFORM X TO VOICE Y. X IN RANGE OF
;                            1-16, Y IN RANGE OF 1-4
;                            (NOTE: CORRESPONDANCE BETWEEN WAVEFORM
;                            NUMBERS AND ACTUAL WAVEFORMS DEFINED WHEN
;                            THE INTERPRETER IS RUN)
;                            (NON-EXECUTABLE) .
;               TPO X        SET TEMPO TO X, X IN RANGE OF 1-255
;                            QUARTER NOTE DURATION (MILLISECONDS) =
;                            X*5.472 (EXECUTABLE)
;               ABS          FORCES ABSOLUTE PITCH IN OBJECT CODE OF THE
;                            NEXT NOTE SOUNDED BY EACH VOICE
;                            (NON-EXECUTABLE)
;               JMP X        UNCONDITIONAL JUMP TO THE LINE WHOSE
;                            IDENTIFIER MATCHES X WHILE PLAYING.
;                            (EXECUTABLE)
;               JSR X        JUMP TO MUSICAL SUBROUTINE TO THE LINE
;                            WHOSE IDENTIFIER MATCHES X WHILE PLAYING.
;                            (EXECUTABLE)
;               RTS          RETURN FROM MUSICAL SUBROUTINE (EXECUTABLE)
;               SUB          DEFINE BEGINNING OF SKIPPED STATEMENT BLOCK
;                            (EXECUTABLE)
;               ESB          DEFINE END OF SKIPPED STATEMENT BLOCK
;                            (EXECUTABLE)
;               END          END OF NOTRAN SOURCE (EXECUTABLE)


;        NOTE SPECIFICATIONS HAVE THE FOLLOWING FORMAT:

;        (OPTIONAL VOICE DIGIT)(NOTE LETTER) (OPTIONAL # OR @) (OPTIONAL
;        OCTAVE NUMBER) (DURATION LETTER) (OPTIONAL DURATION MODIFIER)

;        THE INDIVIDUAL FIELDS ARE AS FOLLOWS:

;        OPTIONAL VOICE DIGIT A DIGIT IN THE RANGE OF 1 TO 4. DOES NOT
;                              REALLY DO ANYTHING BUT WHEN PRESENT IS
;                              COMPARED WITH THE VOICE NUMBER THAT THE
;                              INTERPRETER WOULD ACTUALLY ASSIGN TO THIS
;                              NOTE AND AN ERROR IS SIGNALLED IF THERE
;                              IS A MISMATCH.
;        NOTE LETTER           A, B, C, D, E, F, G ARE LEGAL
;        OPTIONAL # OR @       # FOR A HALF-STEP INCREMENT IN PITCH
;                              @ FOR A HALF-STEP DECREMENT IN PITCH
;        OPTIONAL OCTAVE NUMBER IF PRESENT SPECIFIES THE OCTAVE, RANGE
;                              IS 1-6, C4 IS MIDDLE C, C6 IS HIGHEST
;                              ALLOWABLE NOTE, AN OCTAVE SPANS FROM C TO
;                              B.  IF NOT PRESENT, THE OCTAVE LAST
;                              PLAYED BY THE VOICE IS USED.
;        DURATION LETTER       W = WHOLE, H = HALF, Q = QUARTER,
;                              E = EIGHTH, S = SIXTEENTH, T = THIRTY-
;                              SECOND
;        OPTIONAL DURATION MODIFIER  . SPECIFIES 3/2 OF THE SPECIFIED
;                              DURATION, 3 SPECIFIES 2/3 OF THE
;                              SPECIFIED DURATION.  W.  W3  T3 NOT
;                              AVAILABLE.

;                      RULES FOR ASSIGNING NOTES TO VOICES
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

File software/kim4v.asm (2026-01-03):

;        COPYRIGHT 1977 BY MICRO TECHNOLOGY UNLIMITED, BOX 4596,
;        MANCHESTER, NEW HAMPSHIRE 03108
;        PROGRAM WRITTEN BY HAL CHAMBERLIN

;        THIS PROGRAM PLAYS MUSIC IN 4-PART HARMONY ON THE KIM-1 OR
;        OTHER 6502 BASED SYSTEM USING AN 8-BIT UNSIGNED
;        DIGITAL-TO-ANALOG CONVERTER CONNECTED TO AN OUTPUT PORT.  TUNED
;        FOR SYSTEMS WITH A 1 MHZ CRYSTAL CLOCK.  DOES NOT USE THE ROR
;        INSTRUCTION.

;        SONG TABLE IS AT "SONG" (HEX 0200)
;        ENTRY POINT IS AT "PLAY" (HEX 0100)

;        IN THE SONG TABLE EACH MUSICAL EVENT CONSISTS OF 5 BYTES.  THE
;        FIRST BYTE IS THE DURATION OF THE EVENT IN UNITS ACCORDING TO
;        THE VALUE OF "TEMPO".  FOR A TYPICAL TEMPO SETTING OF 109
;        (DECIMAL) A DURATION OF 48 WOULD CORRESPOND TO A QUARTER NOTE
;        AT APPROXIMATELY 100 BEATS PER MINUTE.
;        IF THE FIRST BYTE IS 0 - 4, THEN A CONTROL FUNCTION IS
;        IS PERFORMED AS FOLLOWS:
;        0      END OF SONG, CONTROL IS RETURNED TO THE KIM MONITOR.
;        1      END OF SONG TABLE SEGMENT, NEXT 2 BYTES CONTAIN ADDRESS
;               OF BEGINNING OF NEXT SEGMENT.
;        2      "REFRAIN DESIGNATOR" (JUMP TO SUBROUTINE) THE CURRENT
;               LOCATION IN THE SONG TABLE IS SAVED ON THE STACK AND THE
;               NEXT 2 BYTES CONTAIN THE ADDRESS OF THE REFRAIN.
;        3      END OF REFRAIN (RETURN FROM SUBROUTINE) PLAYING RESUMES
;               AT THE LOCATION IN THE SONG TABLE SAVED BY THE LAST
;               REFRAIN DESIGNATOR.
;        NOTE:  MUSICAL SUBROUTINES MAY BE STACKED AS DEEP AS DESIRED
;               SUBJECT ONLY TO THE AMOUNT OF STACK AREA AVAILABLE.

;        THE NEXT 4 BYTES ARE NOTE ID NUMBERS FOR THE 4 SIMULTANEOUS
;        VOICES WITH VOICE 1 FIRST.  SEE THE NOTE FREQUENCY TABLE FOR
;        CORRESPONDANCE BETWEEN NUMBERS AND ACTUAL NOTES.

;        THE WAVEFORM TABLE CONTAINS A TABULATION OF THE WAVEFORM TO BE
;        PLAYED BY A VOICE.  WITH A BASIC KIM-1 (1.1K OF MEMORY) ALL
;        VOICES MUST USE THE SAME WAVEFORM.  FOR LARGER MEMORY
;        CONFIGURATIONS EACH VOICE MAY USE A DIFFERENT WAVEFORM TABLE.
;        WHEN USING A DIFFERENT WAVEFORM TABLE FOR VOICE 1 AS AN
;        EXAMPLE, THE PAGE NUMBER OF THE TABLE MUST BE ENTERED AT
;        V1PT+2; LIKEWISE AT V2PT+2 FOR VOICE 2, ETC.   THE AMPLITUDE
;        OF THE WAVEFORM TABULATED MUST BE SUCH THAT WHEN THE 4 VOICES
;        ARE ADDED UP, THERE IS NO POSSIBILITY OF OVERFLOW.  ALSO, THE
;        WAVEFORM SAMPLE VALUES ARE UNSIGNED, POSITIVE NUMBERS.  THE NO
;        OVERFLOW PROVISION IS SATISFIED IF THE LARGEST SAMPLE VALUE IN
;        A WAVEFORM TABLE IS 3F (HEX) OR LESS.  HOWEVER SOME VOICES MAY
;        BE MADE LOUDER THAN OTHERS BY ADJUSTING THE WAVEFORM
;        AMPLITUDES.  NOTE THAT MAXIMUM PERMISSABLE WAVEFORM AMPLITUDE
;        SHOULD ALWAYS BE USED TO MAXIMIZE SIGNAL-TO-NOISE RATIO.

         .zeropage           ; ORG AT PAGE 0 LOCATION 0

DAC      =      $1700        ; OUTPUT PORT ADDRESS WITH DAC
DACDIR   =      $1701        ; DATA DRIECTION REGISTER FOR DAC PORT
AUXRAM   =      $1780        ; ADDRESS OF EXTRA 128 BYTES OF RAM IN 6530

KIMMON   =      $1C22        ; ENTRY POINT TO KIM KEYBOARD MONITOR

V1PT:    .BYTE  0            ; VOICE 1 WAVE POINTER, FRACTIONAL PART
         .BYTE  0            ; INTEGER PART
         .BYTE  >WAV1TB      ; WAVEFORM TABLE PAGE ADDRESS FOR VOICE 1
V2PT:    .BYTE  0            ; SAME AS ABOVE FOR VOICE 2
         .BYTE  0
         .BYTE  >WAV2TB
V3PT:    .BYTE  0            ; SAME AS ABOVE FOR VOICE 3
         .BYTE  0
         .BYTE  >WAV3TB
V4PT:    .BYTE  0            ; SAME AS ABOVE FOR VOICE 4
         .BYTE  0
         .BYTE  >WAV4TB

V1IN:    .WORD  0            ; VOICE 1 INCREMENT (FREQUENCY PARAMETER)
V2IN:    .WORD  0            ; VOICE 2
V3IN:    .WORD  0            ; VOICE 3
V4IN:    .WORD  0            ; VOICE 4

SONGA:   .WORD  SONG         ; ADDRESS OF SONG
TEMPO:   .BYTE  182          ; TEMPO CONTROL VALUE, TYPICAL VALUE FOR
                             ; 4:4 TIME, 60 BEATS PER MINUTE, DURATION
                             ; BYTE = 48 (10) DESIGNATES A QUARTER NOTE

DUR:     .BYTE  0            ; DURATION COUNTER
NOTES:   .WORD  0            ; NOTES POINTER
INCPT:   .WORD  0            ; POINTER FOR LOADING UP V1NT - V4NT
INCA:    .WORD  V1IN         ; INITIAL VALUE OF INCPT
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

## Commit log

2025-12-20 First hardware commit
    [571.stp, K-1002-sound-card-replica.kicad_pcb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]
2025-12-21 Move card design to its own directory
    [571.stp, K-1002-sound-card-replica.kicad_pcb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]
2025-12-21 First commit of the adapter
    [Jumper-green.step, K-1002-kim-adapter.kicad_pcb, K-1002-kim-adapter.kicad_sch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]
2026-01-03 Add software and utilities
    [dwaves.cfg, kim4v.cfg, kimfs.cfg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]
2026-01-05 Add note about the Keystone 571 RCA connector

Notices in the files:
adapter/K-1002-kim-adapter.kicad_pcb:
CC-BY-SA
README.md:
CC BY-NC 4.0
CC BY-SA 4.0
